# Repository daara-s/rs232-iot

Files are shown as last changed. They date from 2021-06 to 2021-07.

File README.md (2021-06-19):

# rs232-iot
RS-232 interface for wireless data acquisition of lab instruments using a Wemos D1 Mini microcontroller

## Goal
[Design an open source board with firmware compatible for data acquisition for a range of commonly used lab instruments](https://www.opencell.bio/summerprojects)

Initial prototyping cost: ~£10
- Wemos D1 Mini: ~£5
    - [Amazon reference](https://www.amazon.co.uk/AZDelivery-Development-ESP8266EX-Compatible-Micropython/dp/B08BTH77F3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)
- RS232 to TTL board: ~£5
    - [Amazon reference](https://www.amazon.co.uk/DollaTek-MAX3232-Serial-Converter-Connector/dp/B07DK3874B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)

### Roadmap
1. Research RS-232 baud rates and communication specifics of different lab instruments
2. Write a program in Arduino to confirm communication over all instrument RS-232 ports
4. Create main MQTT program to parse RS-232 data over WiFi
    * Using [EspMQTTClient](https://github.com/plapointe6/EspMQTTClient) library
5. Produce an RS-232 to TTL PCB shield for the Wemos D1 Mini using KiCAD
6. (optional) Design a 3D printed enclosure for the board in Fusion 360

### Other considerations
- Power: LiPo batteries vs USB vs wall socket
- integrating into existing [OpenCell fermentrack](https://github.com/tmopencell/sudo.bio) system

### RS-232 Shield
Shield board for the Wemos D1 Mini
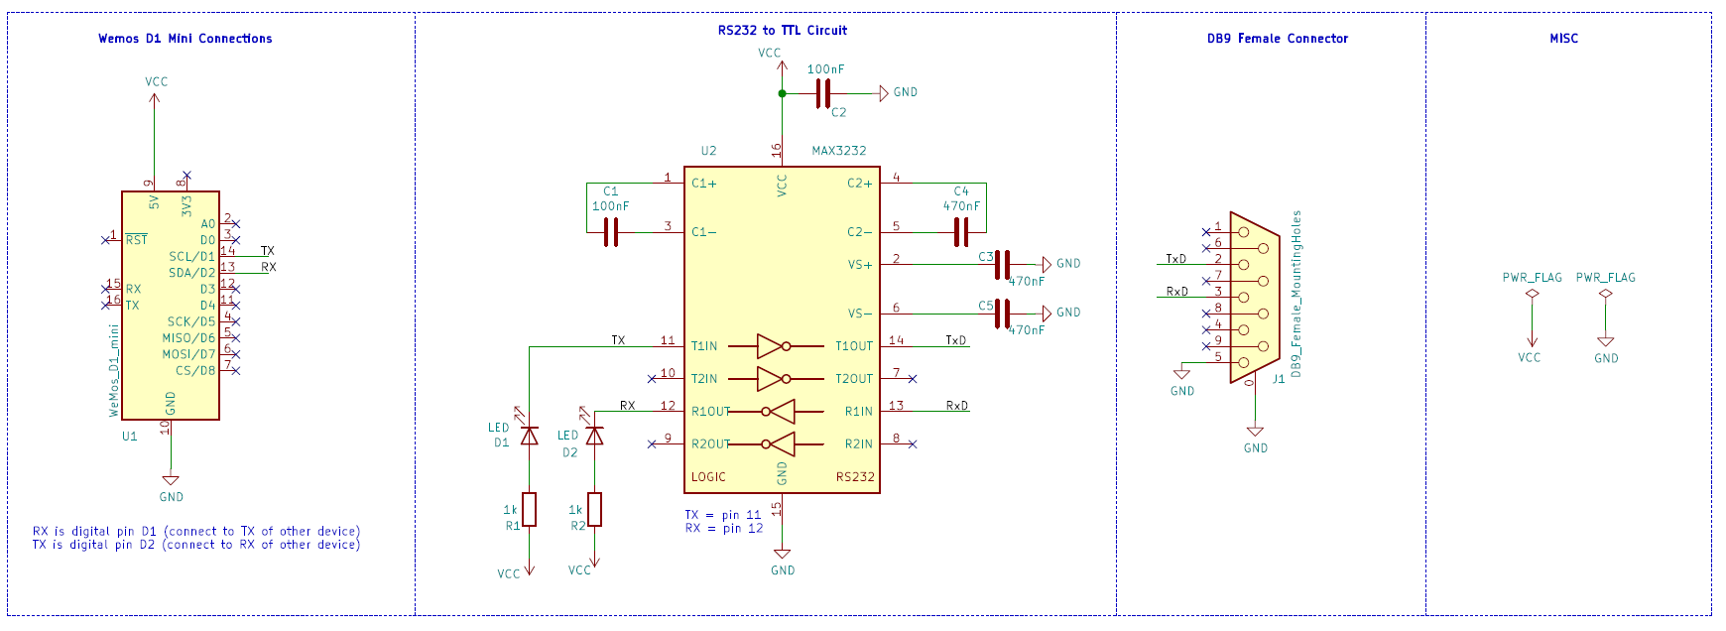
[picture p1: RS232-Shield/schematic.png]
schematic


### References
[Seeedstudio RS-232 to TTL converter](https://wiki.seeedstudio.com/RS-232_To_TTL_Conveter-MAX3232IDR/)
- licensed under: https://creativecommons.org/licenses/by/4.0/

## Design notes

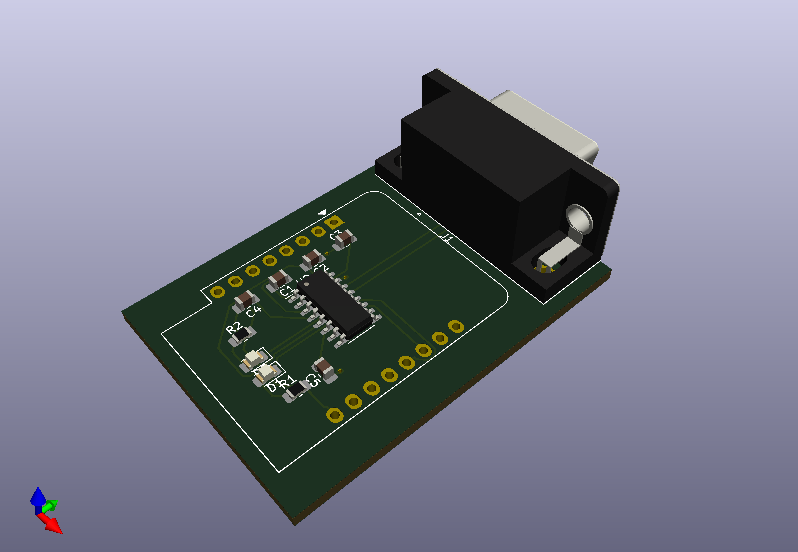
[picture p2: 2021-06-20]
RS232-Shield/RS232-shield.png

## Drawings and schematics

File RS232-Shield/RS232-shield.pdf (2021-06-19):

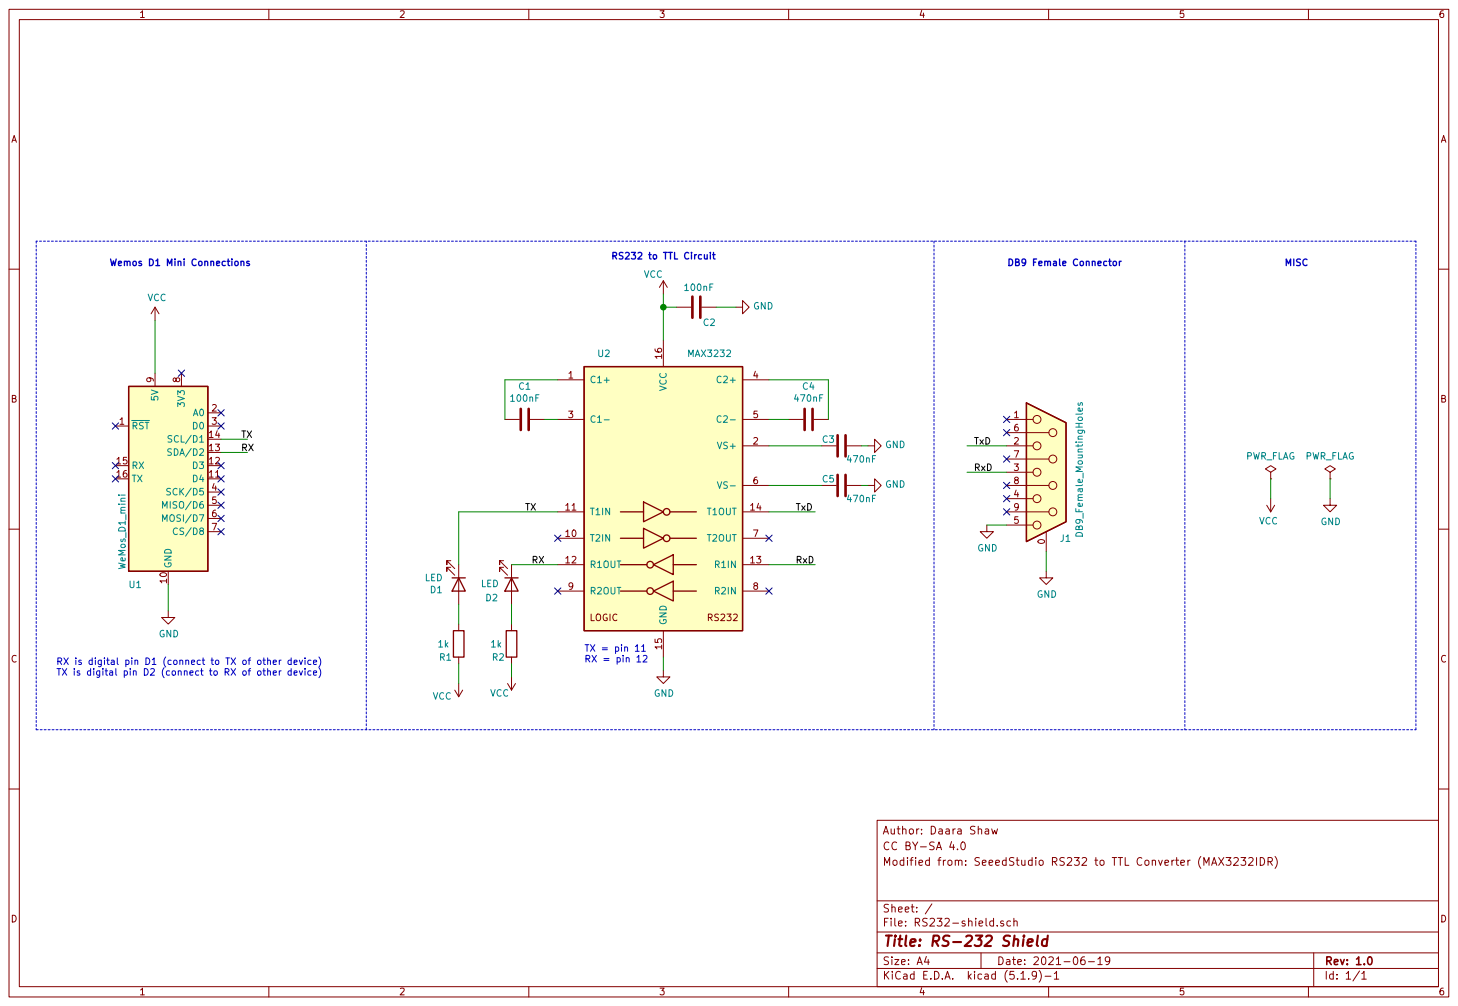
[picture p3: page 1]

RX is digital pin D1 (connect to TX of other device)
TX is digital pin D2 (connect to RX of other device)

File: RS232-shield.sch Sheet: / Modified from: SeeedStudio RS232 to TTL Converter (MAX3232IDR) CC BY-SA 4.0 Author: Daara Shaw

Id: 1/1 Title: RS-232 Shield

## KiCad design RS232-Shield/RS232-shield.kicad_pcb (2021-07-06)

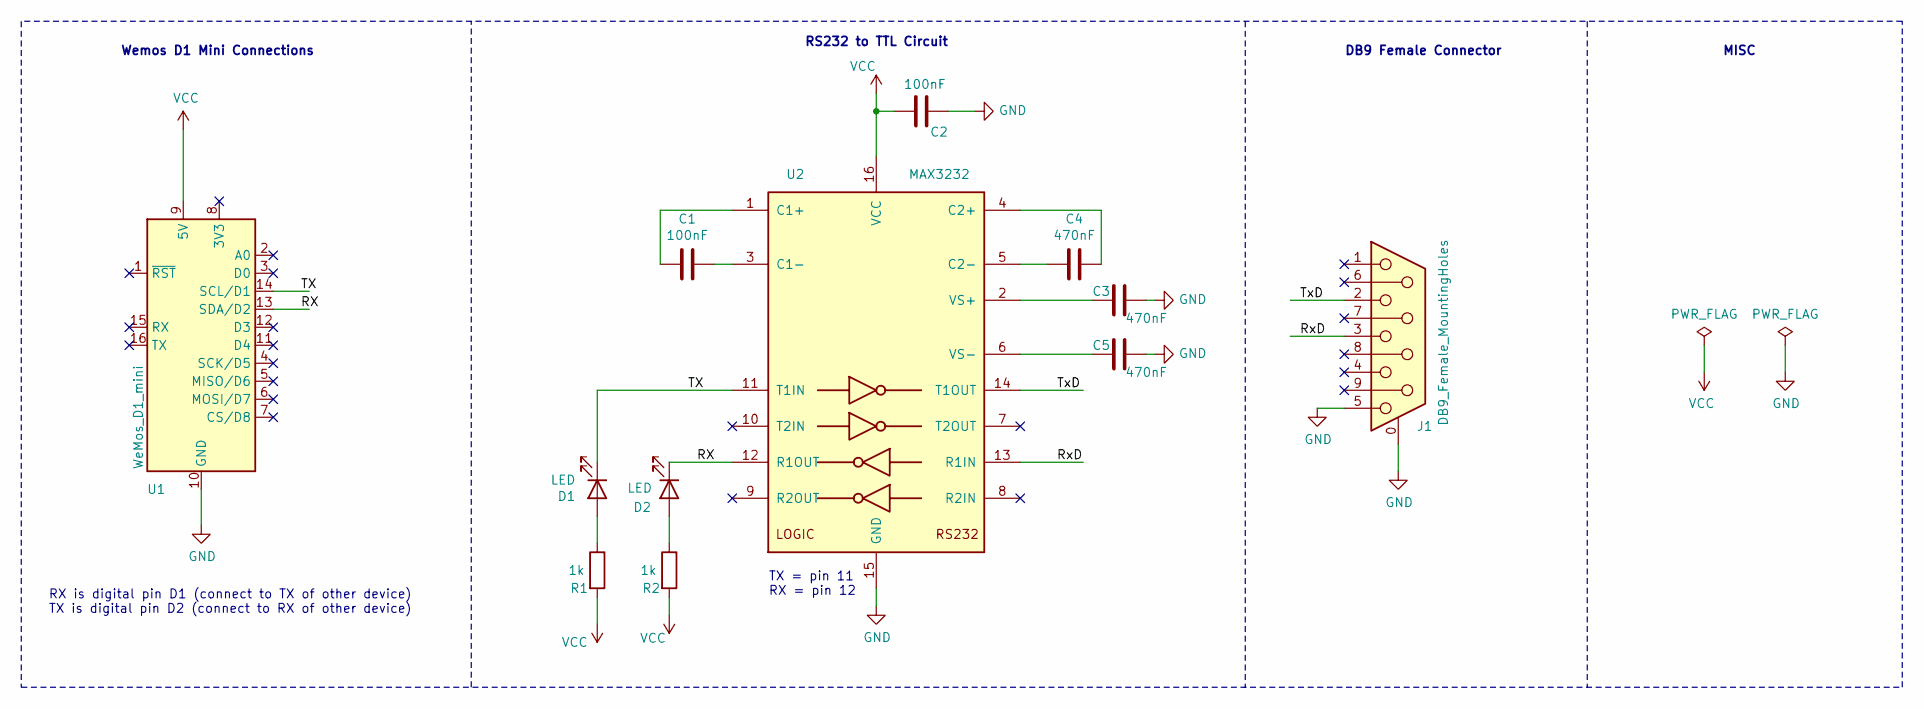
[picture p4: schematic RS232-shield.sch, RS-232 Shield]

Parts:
C1, C2: 100nF; C_0805_2012Metric_Pad1.18x1.45mm_HandSolder
C3, C4, C5: 470nF; C_0805_2012Metric_Pad1.18x1.45mm_HandSolder
D1, D2: LED; LED_0805_2012Metric_Pad1.15x1.40mm_HandSolder
J1: DB9_Female_MountingHoles; DSUB-9_Female_Horizontal_P2.77x2.84mm_EdgePinOffset4.94mm_H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
R1, R2: 1k; R_0805_2012Metric_Pad1.20x1.40mm_HandSolder
U1: WeMos_D1_mini; WEMOS_D1_mini_light
U2: MAX3232; SOIC-16_3.9x9.9mm_P1.27mm

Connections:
/RX: D2.1 (K), U1.13 (SDA/D2), U2.12 (R1OUT)
/RxD: J1.3, U2.13 (R1IN)
/TX: D1.1 (K), U1.14 (SCL/D1), U2.11 (T1IN)
/TxD: J1.2, U2.14 (T1OUT)
GND: C2.1, C3.1, C5.1, J1.0 (PAD), J1.5, U1.10 (GND), U2.15 (GND)
unnamed: C1.1, U2.3 (C1-)
unnamed: C1.2, U2.1 (C1+)
unnamed: C3.2, U2.2 (VS+)
unnamed: C4.1, U2.4 (C2+)
unnamed: C4.2, U2.5 (C2-)
unnamed: C5.2, U2.6 (VS-)
unnamed: D1.2 (A), R1.1
unnamed: D2.2 (A), R2.1
VCC: C2.2, R1.2, R2.2, U1.9 (5V), U2.16 (VCC)

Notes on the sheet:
TX = pin 11 RX = pin 12
RX is digital pin D1 (connect to TX of other device) TX is digital pin D2 (connect to RX of other device)
RS232 to TTL Circuit
Wemos D1 Mini Connections
DB9 Female Connector
MISC

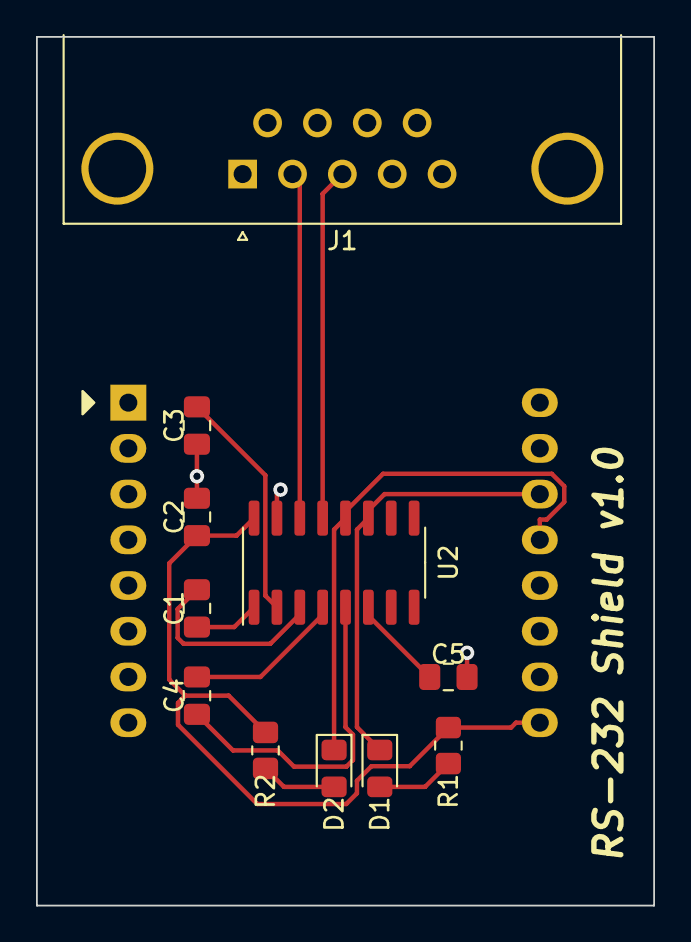
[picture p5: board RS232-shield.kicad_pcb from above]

Board: 2 copper layers, 34.3 x 48.3 mm, 12 parts (0 on the bottom side), 14 nets.

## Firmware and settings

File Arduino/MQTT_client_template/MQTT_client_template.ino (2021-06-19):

/*
  SimpleMQTTClient.ino
  The purpose of this exemple is to illustrate a simple handling of MQTT and Wifi connection.
  Once it connects successfully to a Wifi network and a MQTT broker, it subscribe to a topic and send a message to it.
  It will also send a message delayed 5 seconds later.
*/
/*
 * ESP8266 MQTT client template
 * MQTT libary: https://github.com/plapointe6/EspMQTTClient
 * Program connects to a WiFi network and an MQTT broker, subscribes to a topic and
 * sends RS-232 data to it.
 * Serial Monitor connected for debugging
 */

#include "EspMQTTClient.h"
#include <SoftwareSerial.h>

// Connection for RS-232
SoftwareSerial labSerial(D1, D2); // RX, TX

EspMQTTClient client(
  "WifiSSID",
  "WifiPassword",
  "192.168.1.100",  // MQTT Broker server ip
  "MQTTUsername",   // Can be omitted if not needed
  "MQTTPassword",   // Can be omitted if not needed
  "TestClient",     // Client name that uniquely identify your device
  1883              // The MQTT port, default to 1883. this line can be omitted
);

void setup()
{
  Serial.begin(115200);
  while (!Serial) {
    ; // wait for serial port to connect.
  }
  Serial.println("Monitor Connected");

  // set the data rate for the SoftwareSerial port
  labSerial.begin(4800); // baud rate for connected lab instrument
  labSerial.println("AT"); // initial AT command(s) to send to RS-232 port

  // Optionnal functionnalities of EspMQTTClient :
  client.enableDebuggingMessages(); // Enable debugging messages sent to serial output
  client.enableHTTPWebUpdater(); // Enable the web updater. User and password default to values of MQTTUsername and MQTTPassword. These can be overrited with enableHTTPWebUpdater("user", "password").
  client.enableLastWillMessage("TestClient/lastwill", "I am going offline");  // You can activate the retain flag by setting the third parameter to true
}

// This function is called once everything is connected (Wifi and MQTT)
// WARNING : YOU MUST IMPLEMENT IT IF YOU USE EspMQTTClient
void onConnectionEstablished()
{
  // Modify depending on data sent via RS-232
  
  // Subscribe to "mytopic/test" and display received message to Serial
  client.subscribe("mytopic/test", [](const String & payload) {
    Serial.println(payload);
  });

  // Publish a message to "mytopic/test"
  client.publish("mytopic/test", "This is a message"); // You can activate the retain flag by setting the third parameter to true

}

void loop()
{
  client.loop();
}

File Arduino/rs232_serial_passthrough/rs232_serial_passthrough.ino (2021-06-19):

/*
  Wemos D1 Mini to RS-232 Serial passthrough
 
 Receives from the hardware serial, sends to software serial.
 Receives from software serial, sends to hardware serial.
 
 The circuit: 
 * RX is digital pin D1 (connect to TX of other device)
 * TX is digital pin D2 (connect to RX of other device)
 
 Note:
 All pins on Wemos D1 Mini support interrupts,
 except GPIO16(D0)
 
 */
#include <SoftwareSerial.h>

// Connection for RS-232
SoftwareSerial labSerial(D1, D2); // RX, TX

void setup()  
{
  // Open serial monitor communications and wait for port to open:
  Serial.begin(57600);
  while (!Serial) {
    ; // wait for serial port to connect.
  }


  Serial.println("Monitor Connected");

  // set the data rate for the SoftwareSerial port
  labSerial.begin(4800); // baud rate for connected lab instrument
  labSerial.println("AT"); // initial AT command(s) to send to RS-232 port
}

void loop()
{
  // parse data between Arduino Serial Monitor and RS-232 port
  if (labSerial.available())
    Serial.write(labSerial.read());
  if (Serial.available())
    labSerial.write(Serial.read());
}

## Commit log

2021-06-17 Add RS232 to TTL schematic and board layout
    Source: https://wiki.seeedstudio.com/RS-232_To_TTL_Conveter-MAX3232IDR/
    [RS232 to TTL Converter (MAX3232IDR).brd, RS232 to TTL Converter (MAX3232IDR).sch]
2021-06-17 Rename RS232 to TTL Converter (MAX3232IDR).brd to rs232/RS232 to TTL Converter (MAX3232IDR).brd
    [RS232 to TTL Converter (MAX3232IDR).brd]
2021-06-17 Rename RS232 to TTL Converter (MAX3232IDR).sch to rs232/RS232 to TTL Converter (MAX3232IDR).sch
    [RS232 to TTL Converter (MAX3232IDR).sch]
2021-06-18 Add references section
    Moved schematic to references section
2021-06-19 Add RS-232 Shield Schematic
    Schematic for an RS-232 shield to mount on a Wemos D1 Mini board via headers
    [RS232-shield.sch]
2021-06-19 Reorganise folder structure, add shield schematic image
    [RS232 to TTL Converter (MAX3232IDR).brd, RS232 to TTL Converter (MAX3232IDR).sch]
2021-06-20 Add RS-232 Shield PCB layout
    [RS232-shield.kicad_pcb, RS232-shield.sch]
2021-07-06 Modify PCB silkscreens
    Project-specific footprint added for Wemos D1 Mini
    [RS232-shield.sch]
2021-07-06 Add board name to silkscreen
    [RS232-shield.kicad_pcb]
